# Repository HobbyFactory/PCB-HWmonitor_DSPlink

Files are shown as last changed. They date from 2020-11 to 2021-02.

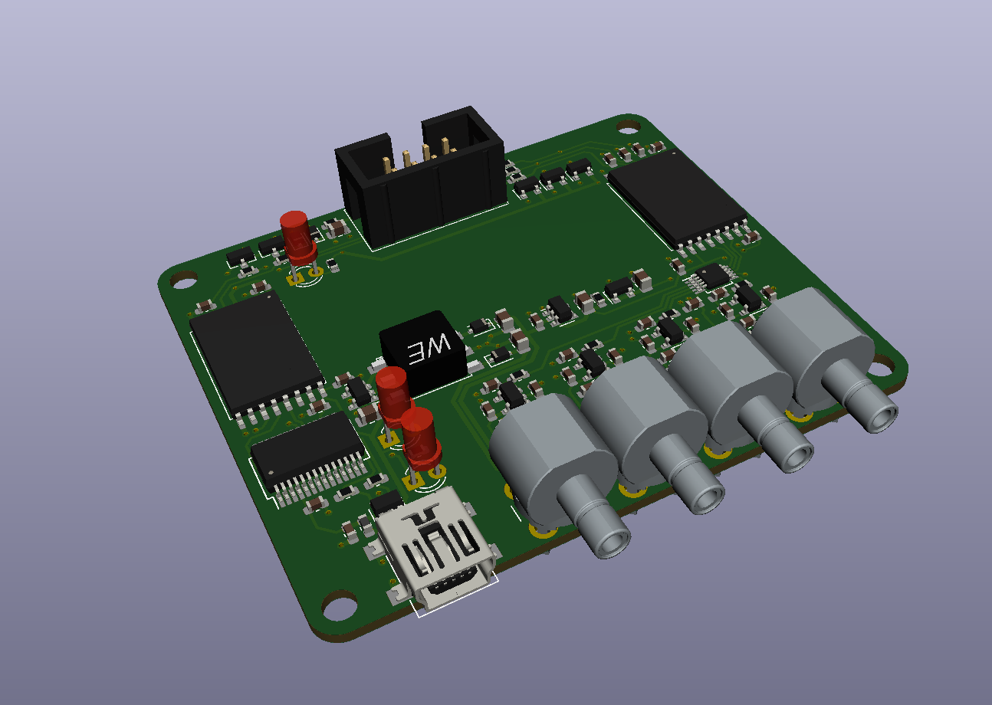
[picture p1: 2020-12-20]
gerber/picutre.PNG

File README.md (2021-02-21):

# HWmonitor & DSPlink

This is a debug tool, for visualizing digital signals from DSP or Microcontroller on Oscilloscope screen. In adition contains USB<->Serial converter to allow debug 
communication with target device.

block_diagram

Heart of the device is fast SPI D/A converter AD5324ARMZ, converting 4 channels into analog values, post processed by operational amplifiers. High voltage 8kVrms (ISO78XXDWW) galvanic isolation is provided between all inputs/outputs, to ensure safe debug experience, especially with high voltage power converters. 

Schematic, PCB project in KiCad and BOM are included in this repository. Device does not require any firmware for operation.

Model of the box optimized for 3D printer you can find here:
https://www.thingiverse.com/thing:4769601

If you are interested, send me the message, I still have some PCBs left from JLC.PCB. Assembled and tested version is available too.

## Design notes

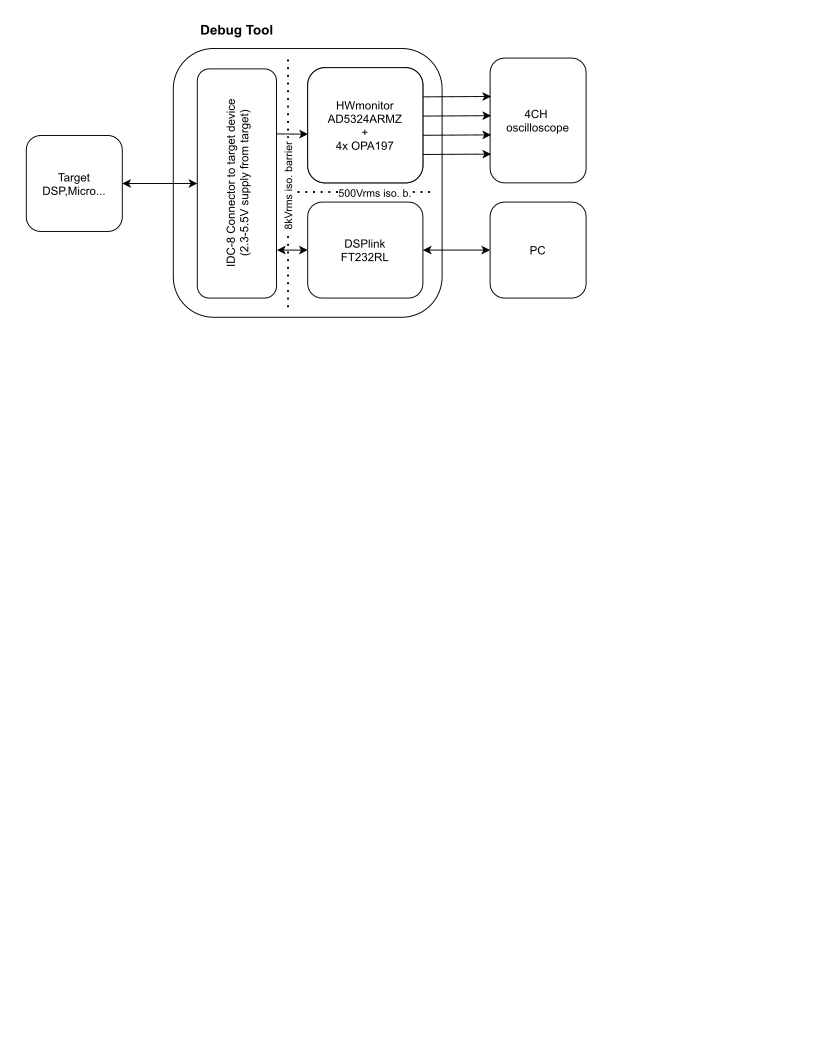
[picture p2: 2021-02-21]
blockd/png.png

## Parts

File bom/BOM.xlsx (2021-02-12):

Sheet: by MPNs
Item | Qty | Reference(s) | Value | Footprint | MPN
1 | 22 | C1, C5, C6, C10, C11, C12, C13, C14, C19, C20, C21, C22, C23, C28, C29, C30, C31, C32, C33, C34, C35, C36 | 100nF/50V | Capacitor_SMD:C_0603_1608Metric
2 | 6 | C2, C9, C15, C16, C17, C18 | 10uF/16V | Capacitor_SMD:C_0805_2012Metric | CC0805MKX7R7BB106
3 | 4 | C3, C4, C7, C8 | - | Capacitor_SMD:C_0603_1608Metric | -
4 | 4 | C24, C25, C26, C27 | 68pF/50V | Capacitor_SMD:C_0603_1608Metric
5 | 5 | D1, D3, D6, D7, D8 | BAT54S | Package_TO_SOT_SMD:SOT-23 | BAT54S
6 | 3 | D2, D11, D12 | PMEG6010CEJ | Diode_SMD:D_SOD-323F | PMEG6010CEJ
7 | 1 | D4 | 5.1V/200mW | Diode_SMD:D_SOD-323F | MM3Z5V1C
8 | 3 | D5, D9, D10 | RED | LED_THT:LED_D3.0mm_FlatTop | WP424SRDT
9 | 4 | H1, H2, H3, H4 | MountingHole | MountingHole:MountingHole_3.2mm_M3 | PHANTOM
10 | 1 | J1 | Mini USB-B | Connector_USB:USB_Mini-B_Lumberg_2486_01_Horizontal | 65100516121
11 | 1 | J2 | IDC-Header 2x4 | Connector_IDC:IDC-Header_2x04_P2.54mm_Vertical | 61200821621
12 | 1 | L1 | 1k@100MHz | Inductor_SMD:L_0603_1608Metric | 742792664
13 | 13 | R1, R2, R5, R6, R7, R11, R12, R13, R14, R23, R24, R25, R26 | 10R | Resistor_SMD:R_0603_1608Metric
14 | 1 | R3 | 27R | Resistor_SMD:R_0603_1608Metric
15 | 2 | R4, R8, R9 | 270R | Resistor_SMD:R_0603_1608Metric
16 | 1 | R10 | 750R | Resistor_SMD:R_0603_1608Metric
17 | 8 | R15, R16, R17, R18, R19, R20, R21, R22 | 10k | Resistor_SMD:R_0603_1608Metric
18 | 2 | R27, R28 | 47R | Resistor_SMD:R_0603_1608Metric
19 | 1 | T1 | 760390014 | #MyLibrary:Wuerth_760390014 | 760390014
20 | 1 | U1 | FT232RL | Package_SO:SSOP-28_5.3x10.2mm_P0.65mm | FT232RL
21 | 1 | U2 | ISO7830DWW | #MyLibrary:SOIC-16DWW | ISO7830DWW
22 | 1 | U3 | ISO7821DWW | #MyLibrary:SOIC-16DWW | ISO7821DWW
23 | 1 | U4 | SN6501DBVR | Package_TO_SOT_SMD:SOT-23-5 | SN6501DBVR
24 | 1 | U5 | TL431BCDBZ | Package_TO_SOT_SMD:SOT-23 | TL431BCDBZ
25 | 1 | U6 | AD5324ARMZ | Package_SO:MSOP-10_3x3mm_P0.5mm | AD5324ARMZ
26 | 1 | U7 | TLV70450DBVT | Package_TO_SOT_SMD:SOT-23-5 | TLV70450DBVT
27 | 4 | U8, U9, U10, U11 | OPA197xDBV | Package_TO_SOT_SMD:SOT-23-5 | OPA197IDBV
28 | 1 | U12 | USBLC6-2SC6 | Package_TO_SOT_SMD:SOT-23-6 | USBLC6-2SC6
29 | 4 | X1, X2, X3, X4 | Conn_Coaxial | #MyLibrary:Connector_131-3701-301 | 131-3701-301 OR 731000103

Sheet: by Components
Reference(s) | Value | MPN
C1 | 100nF/50V
C2 | 10uF/16V | CC0805MKX7R7BB106
C3 | NM
C4 | NM
C5 | 100nF/50V
C6 | 100nF/50V
C7 | NM
C8 | NM
C9 | 10uF/16V | CC0805MKX7R7BB106
C10 | 100nF/50V
C11 | 100nF/50V
C12 | 100nF/50V
C13 | 100nF/50V
C14 | 100nF/50V
C15 | 10uF/16V | CC0805MKX7R7BB106
C16 | 10uF/16V | CC0805MKX7R7BB106
C17 | 10uF/16V | CC0805MKX7R7BB106
C18 | 10uF/16V | CC0805MKX7R7BB106
C19 | 100nF/50V
C20 | 100nF/50V
C21 | 100nF/50V
C22 | 100nF/50V
C23 | 100nF/50V
C24 | 68pF/50V
C25 | 68pF/50V
C26 | 68pF/50V
C27 | 68pF/50V
C28 | 100nF/50V
C29 | 100nF/50V
C30 | 100nF/50V
C31 | 100nF/50V
C32 | 100nF/50V
C33 | 100nF/50V
C34 | 100nF/50V
C35 | 100nF/50V
C36 | 100nF/50V
D1 | BAT54S | BAT54S
D2 | PMEG6010CEJ | PMEG6010CEJ
D3 | BAT54S | BAT54S
D4 | 5.1V/200mW | MM3Z5V1C
D5 | RED | WP424SRDT
D6 | BAT54S | BAT54S
D7 | BAT54S | BAT54S
D8 | BAT54S | BAT54S
D9 | RED | WP424SRDT
D10 | RED | WP424SRDT
D11 | PMEG6010CEJ | PMEG6010CEJ
D12 | PMEG6010CEJ | PMEG6010CEJ
H1 | MountingHole | PHANTOM
H2 | MountingHole | PHANTOM
H3 | MountingHole | PHANTOM
H4 | MountingHole | PHANTOM
J1 | Mini USB-B | 65100516121
J2 | IDC-Header 2x4 | 61200821621
L1 | 1k@100MHz | 742792664
R1 | 10R
R2 | 10R
R3 | 27R
R4 | 10R
R5 | 10R
R6 | 10R
R7 | 10R
R8 | 270R
R9 | 270R
R10 | 750R
R11 | 10R
R12 | 10R
R13 | 10R
R14 | 10R
R15 | 10k
R16 | 10k
R17 | 10k
R18 | 10k
R19 | 10k
R20 | 10k
R21 | 10k
R22 | 10k
R23 | 10R
R24 | 10R
R25 | 10R
R26 | 10R
R27 | 47R
R28 | 47R
T1 | 760390014 | 760390014
U1 | FT232RL | FT232RL
U2 | ISO7830DWW | ISO7830DWW
U3 | ISO7821DWW | ISO7821DWW
U4 | SN6501DBVR | SN6501DBVR
U5 | TL431BCDBZ | TL431BCDBZ
U6 | AD5324ARMZ | AD5324ARMZ
U7 | TLV70450DBVT | TLV70450DBVT
U8 | OPA197xDBV | OPA197IDBV
U9 | OPA197xDBV | OPA197IDBV
U10 | OPA197xDBV | OPA197IDBV
U11 | OPA197xDBV | OPA197IDBV
U12 | USBLC6-2SC6 | USBLC6-2SC6
X1 | Conn_Coaxial | 131-3701-301
X2 | Conn_Coaxial | 131-3701-301
X3 | Conn_Coaxial | 131-3701-301
X4 | Conn_Coaxial | 131-3701-301

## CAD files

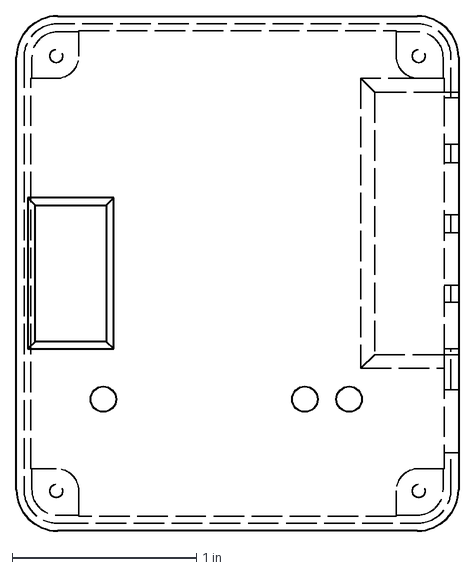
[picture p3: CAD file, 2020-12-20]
cad/box.dxf
2.40 x 2.80 in

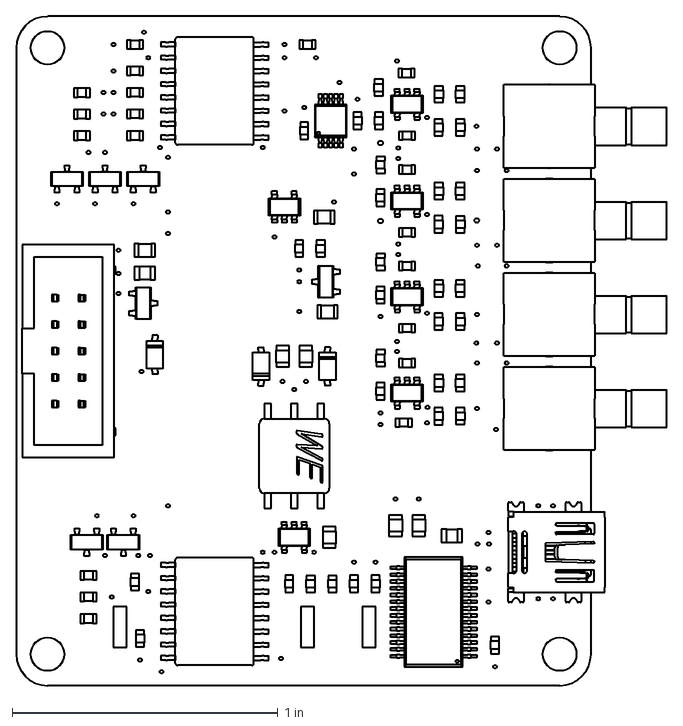
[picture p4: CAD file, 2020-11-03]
cad/HWmonitor v14_BelConnectors.dxf
2.45 x 2.52 in

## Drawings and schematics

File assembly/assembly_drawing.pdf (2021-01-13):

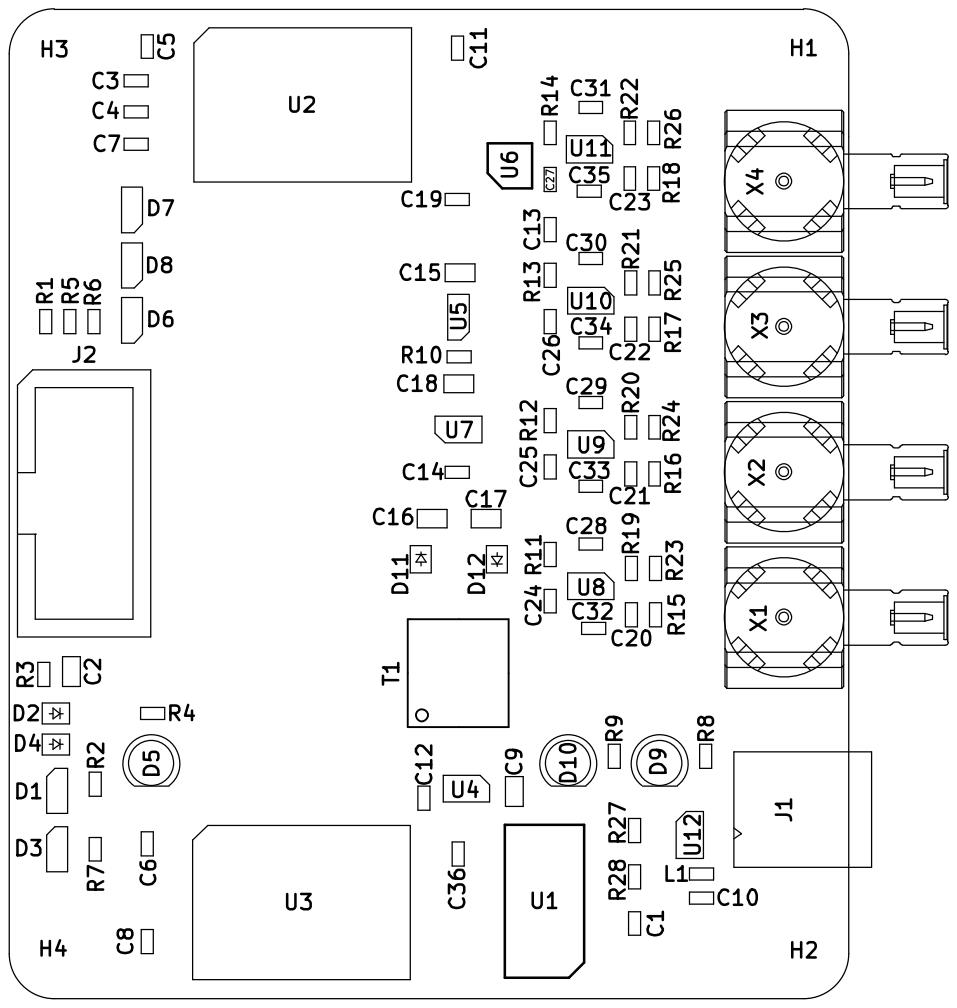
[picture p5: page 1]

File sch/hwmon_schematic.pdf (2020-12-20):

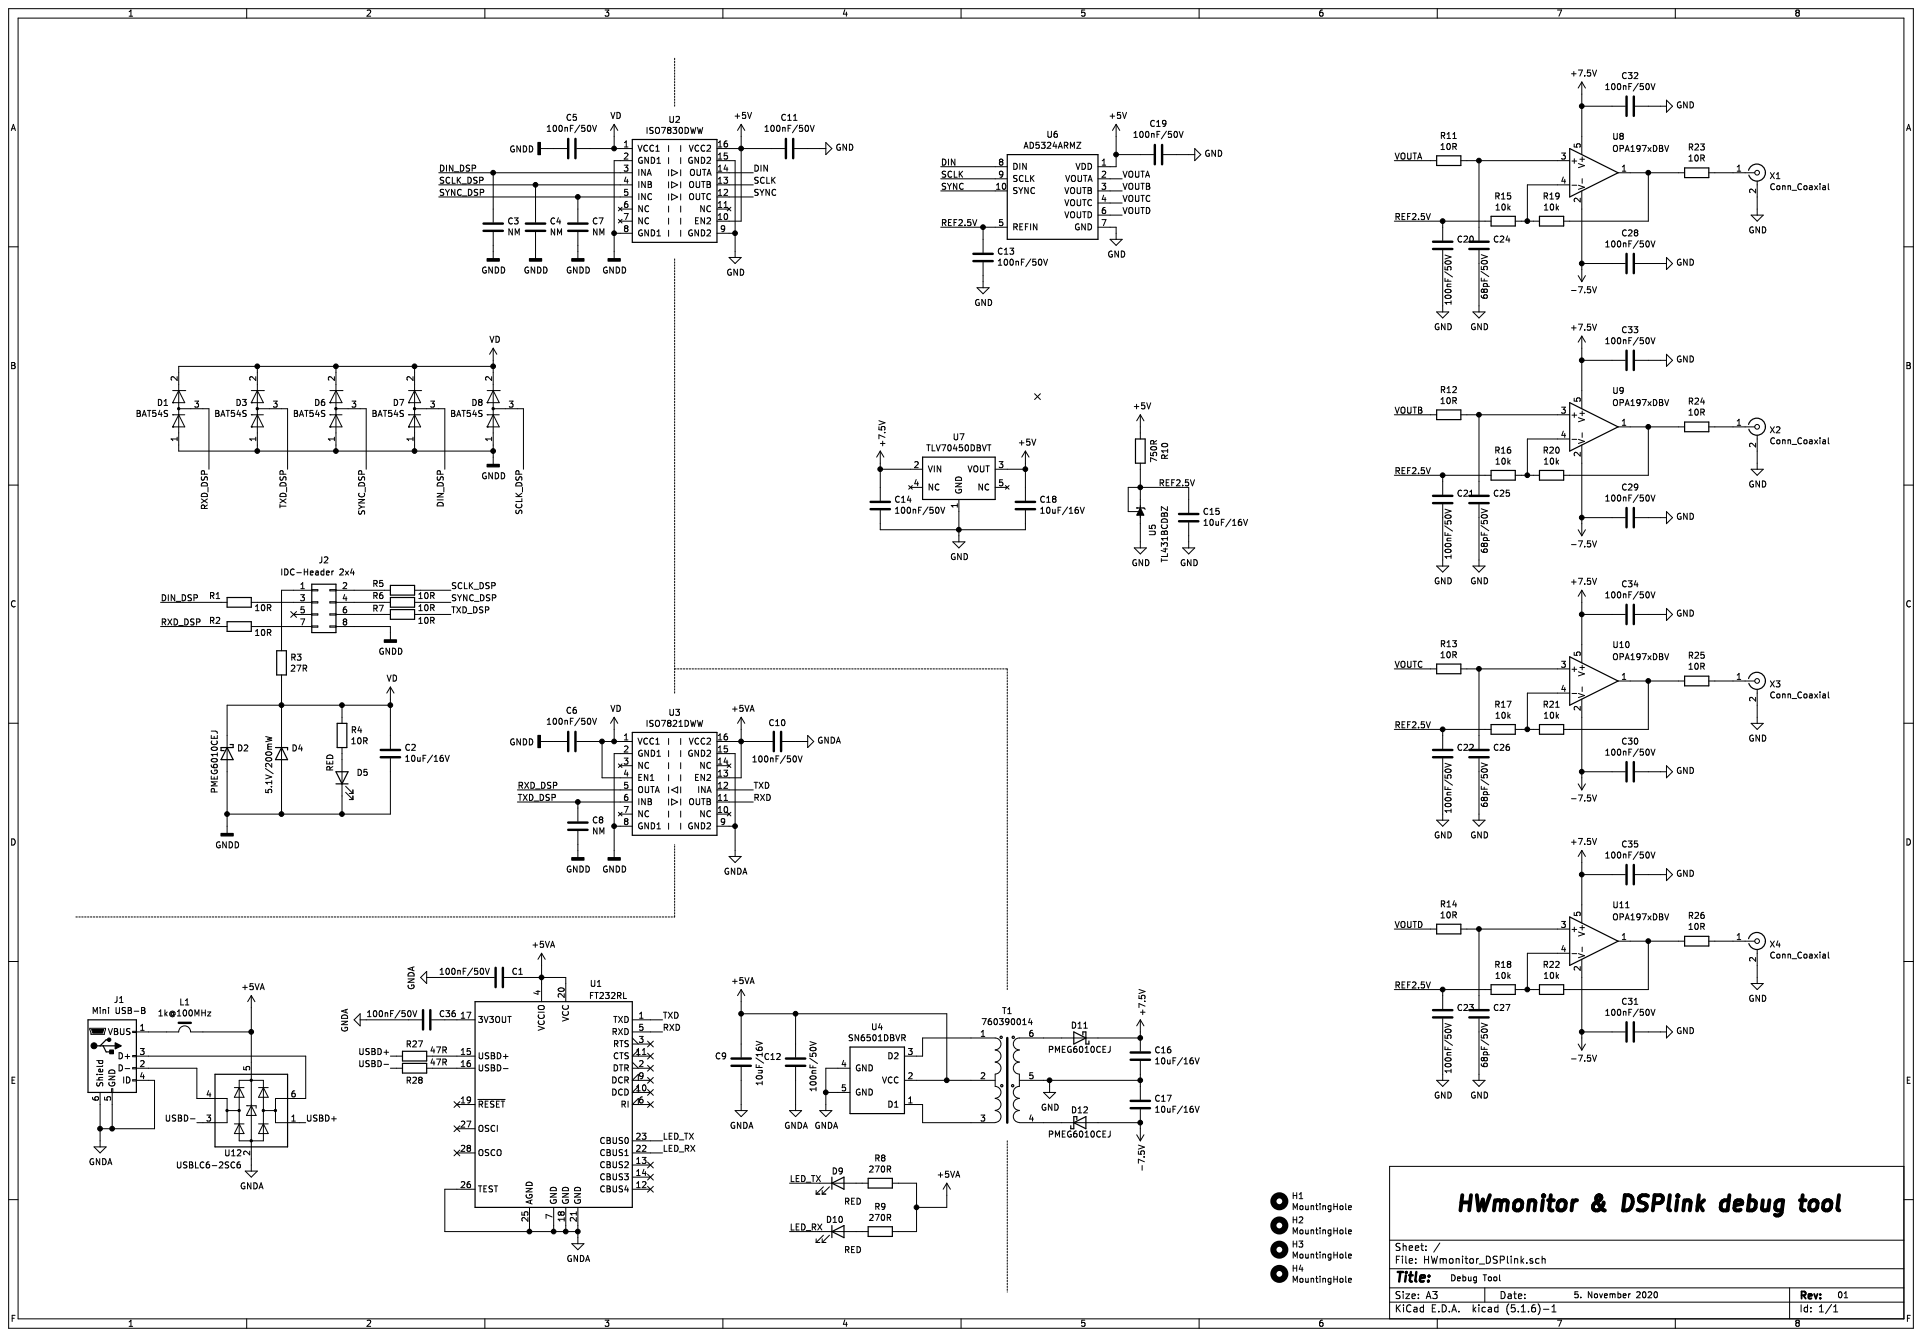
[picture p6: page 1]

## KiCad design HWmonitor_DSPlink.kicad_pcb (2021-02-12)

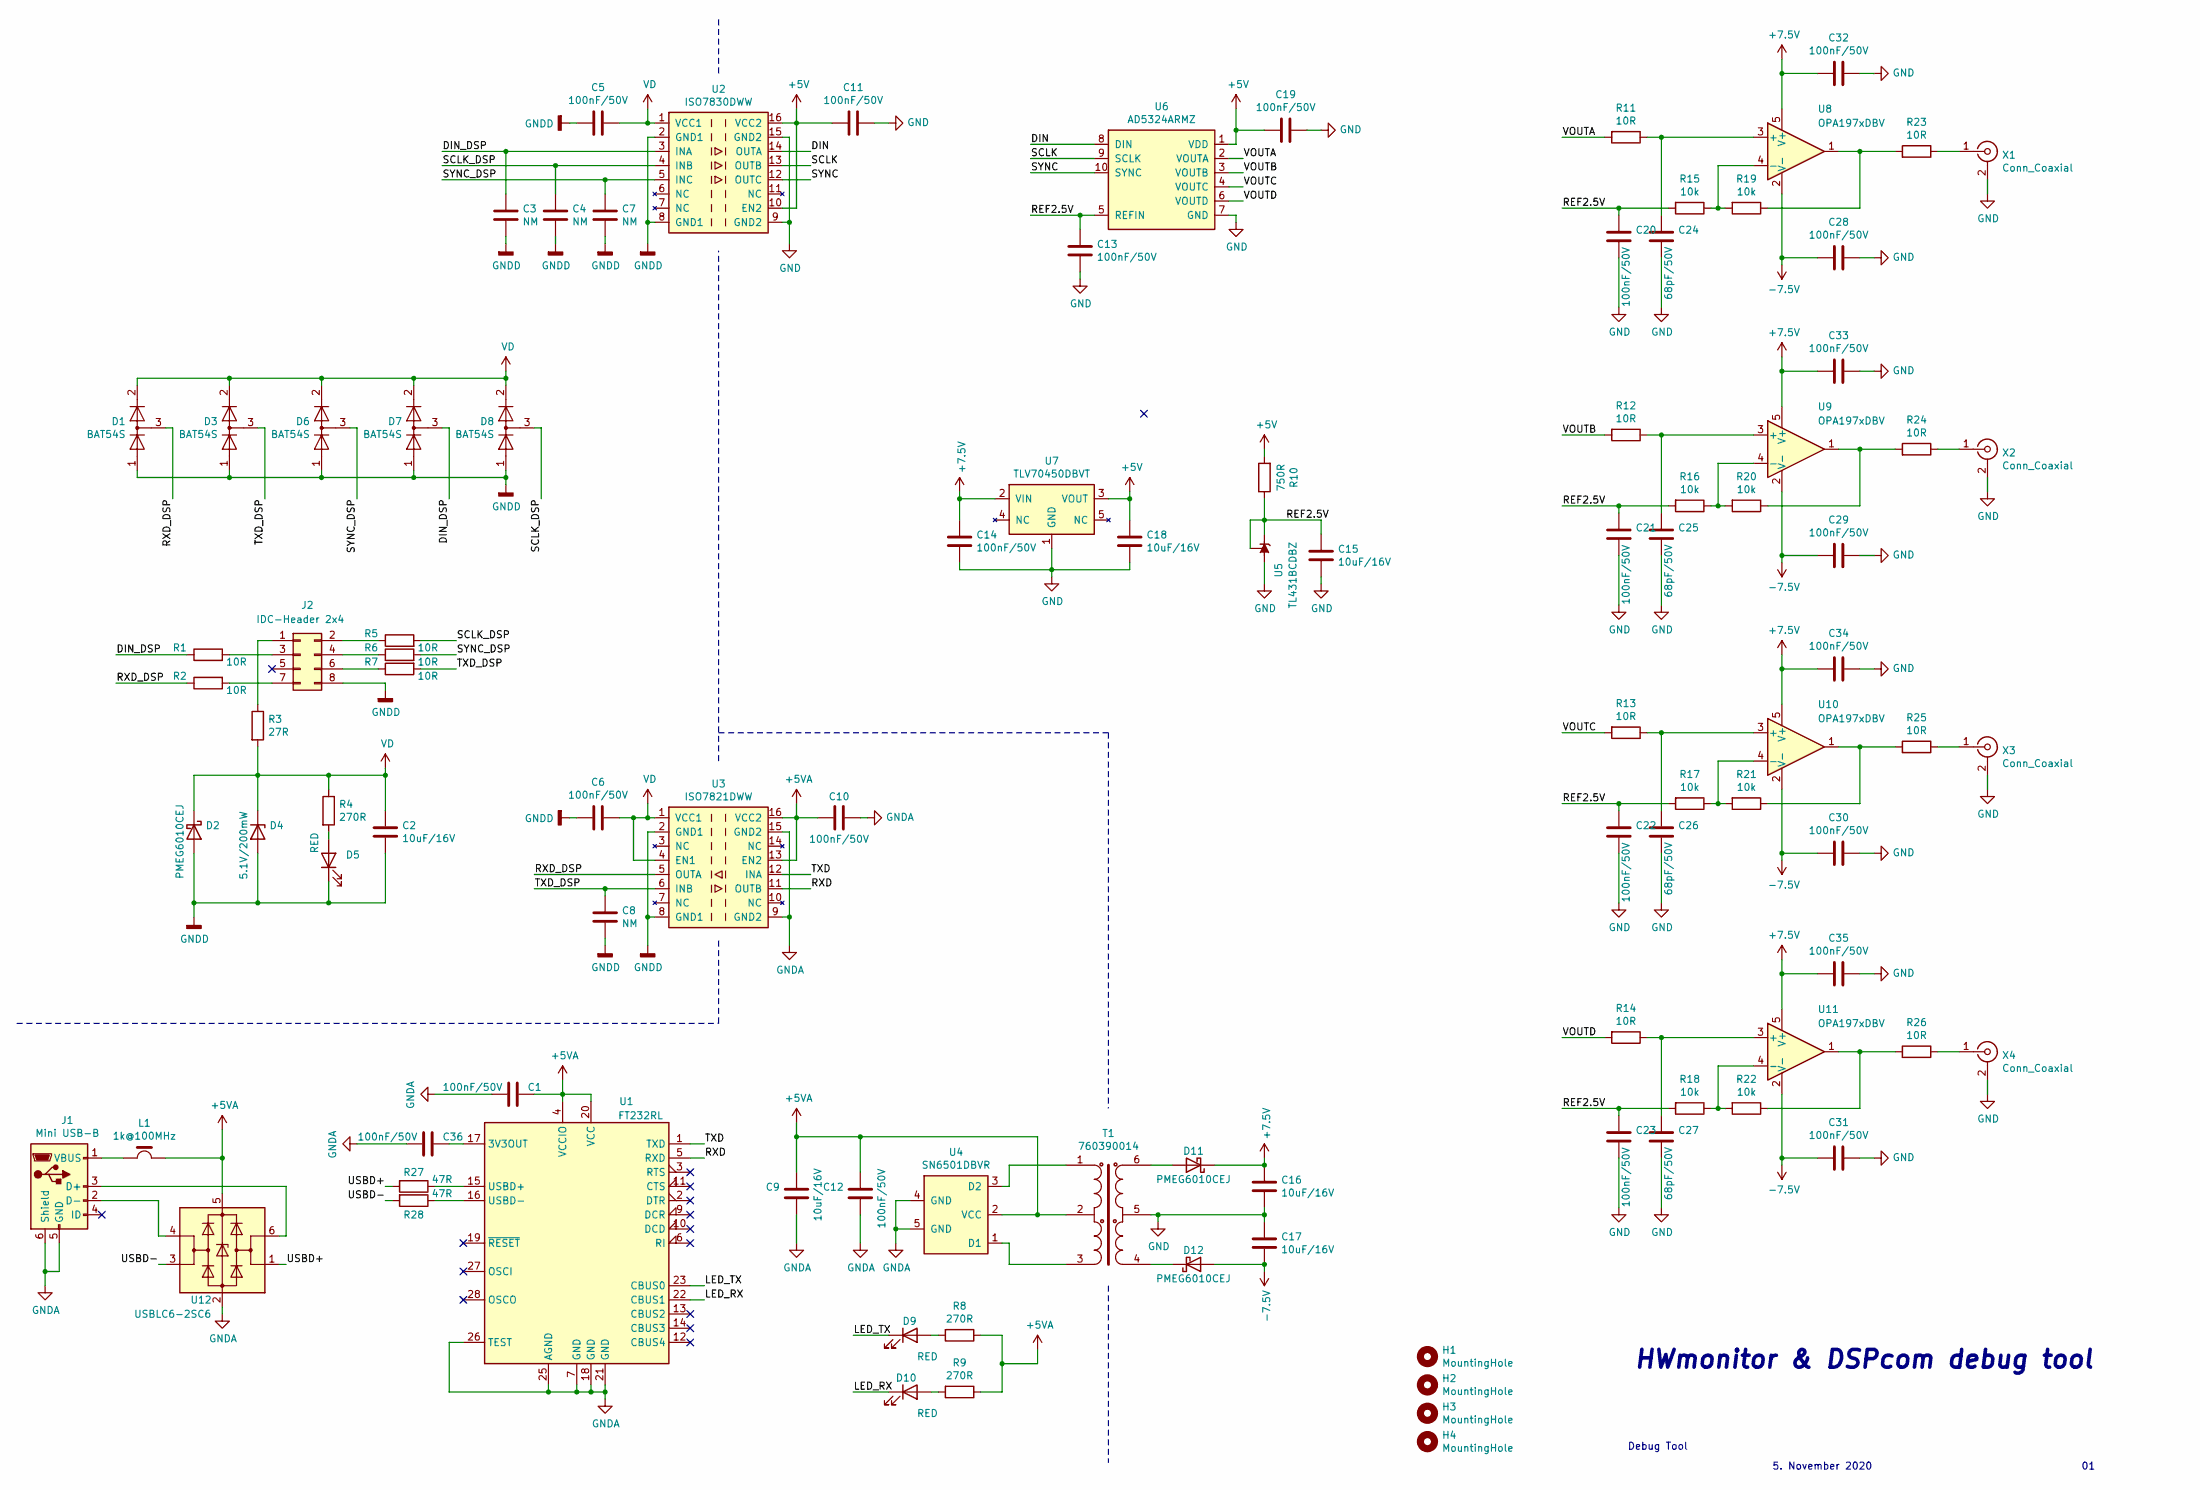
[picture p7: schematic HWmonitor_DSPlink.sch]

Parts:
C1, C5, C6, C10, C11, C12, C13, C14, C19, C20, C21, C22, C23, C28, C29, C30, C31, C32, C33, C34, C35, C36: 100nF/50V; C_0603_1608Metric
C2, C9, C15, C16, C17, C18: 10uF/16V; C_0805_2012Metric; MPN CC0805MKX7R7BB106
C3, C4, C7, C8: NM; C_0603_1608Metric
C24, C25, C26, C27: 68pF/50V; C_0603_1608Metric
D1, D3, D6, D7, D8: BAT54S; SOT-23; MPN BAT54S
D2, D11, D12: PMEG6010CEJ; D_SOD-323F; MPN PMEG6010CEJ
D4: 5.1V/200mW; D_SOD-323F; MPN MM3Z5V1C
D5, D9, D10: RED; LED_D3.0mm_FlatTop; MPN WP424SRDT
H1, H2, H3, H4: MountingHole; MountingHole_3.2mm_M3; MPN PHANTOM
J1: Mini USB-B; USB_Mini-B_Lumberg_2486_01_Horizontal; MPN 65100516121
J2: IDC-Header 2x4; IDC-Header_2x04_P2.54mm_Vertical; MPN 61200821621
L1: 1k@100MHz; L_0603_1608Metric; MPN 742792664
R1, R2, R5, R6, R7, R11, R12, R13, R14, R23, R24, R25, R26: 10R; R_0603_1608Metric
R3: 27R; R_0603_1608Metric
R4, R8, R9: 270R; R_0603_1608Metric
R10: 750R; R_0603_1608Metric
R15, R16, R17, R18, R19, R20, R21, R22: 10k; R_0603_1608Metric
R27, R28: 47R; R_0603_1608Metric
T1: 760390014; Wuerth_760390014; MPN 760390014
U1: FT232RL; SSOP-28_5.3x10.2mm_P0.65mm; MPN FT232RL
U2: ISO7830DWW; SOIC-16DWW; MPN ISO7830DWW
U3: ISO7821DWW; SOIC-16DWW; MPN ISO7821DWW
U4: SN6501DBVR; SOT-23-5; MPN SN6501DBVR
U5: TL431BCDBZ; SOT-23; MPN TL431BCDBZ
U6: AD5324ARMZ; MSOP-10_3x3mm_P0.5mm; MPN AD5324ARMZ
U7: TLV70450DBVT; SOT-23-5; MPN TLV70450DBVT
U8, U9, U10, U11: OPA197xDBV; SOT-23-5; MPN OPA197IDBV
U12: USBLC6-2SC6; SOT-23-6; MPN USBLC6-2SC6
X1, X2, X3, X4: Conn_Coaxial; Connector_131-3701-301; MPN 131-3701-301

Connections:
+5V: C11.1, C18.2, C19.1, R10.2, U2.10 (EN2), U2.16 (VCC2), U6.1 (VDD), U7.3 (VOUT)
+5VA: C1.2, C9.2, C10.1, C12.1, L1.2, R8.1, R9.1, T1.2, U1.4 (VCCIO), U1.20 (VCC), U3.13 (EN2), U3.16 (VCC2), U4.2 (VCC), U12.5 (VBUS)
+7.5V: C14.2, C16.2, C32.2, C33.2, C34.2, C35.2, D11.1 (K), U7.2 (VIN), U8.5 (V+), U9.5 (V+), U10.5 (V+), U11.5 (V+)
-7.5V: C17.1, C28.2, C29.2, C30.2, C31.2, D12.2 (A), U8.2 (V-), U9.2 (V-), U10.2 (V-), U11.2 (V-)
/DIN: U2.14 (OUTA), U6.8 (DIN)
/DIN_DSP: C3.2, D7.3 (K), R1.1, U2.3 (INA)
/LED_RX: D10.1 (K), U1.22 (CBUS1)
/LED_TX: D9.1 (K), U1.23 (CBUS0)
/REF2.5V: C13.2, C15.2, C20.2, C21.2, C22.2, C23.2, R10.1, R15.2, R16.2, R17.2, R18.2, U5.1 (K), U5.2 (REF), U6.5 (REFIN)
/RXD: U1.5 (RXD), U3.11 (OUTB)
/RXD_DSP: D1.3 (K), R2.1, U3.5 (OUTA)
/SCLK: U2.13 (OUTB), U6.9 (SCLK)
/SCLK_DSP: C4.2, D8.3 (K), R5.2, U2.4 (INB)
/SYNC: U2.12 (OUTC), U6.10 (SYNC)
/SYNC_DSP: C7.2, D6.3 (K), R6.2, U2.5 (INC)
/TXD: U1.1 (TXD), U3.12 (INA)
/TXD_DSP: C8.2, D3.3 (K), R7.2, U3.6 (INB)
/USBD+: R27.2, U12.1 (I/O1)
/USBD-: R28.2, U12.3 (I/O2)
/VOUTA: R11.2, U6.2 (VOUTA)
/VOUTB: R12.2, U6.3 (VOUTB)
/VOUTC: R13.2, U6.4 (VOUTC)
/VOUTD: R14.2, U6.6 (VOUTD)
GND: C11.2, C13.1, C14.1, C15.1, C16.1, C17.2, C18.1, C19.2, C20.1, C21.1, C22.1, C23.1, C24.1, C25.1, C26.1, C27.1, C28.1, C29.1, C30.1, C31.1, C32.1, C33.1, C34.1, C35.1, T1.5, U2.9 (GND2), U2.15 (GND2), U5.3 (A), U6.7 (GND), U7.1 (GND), X1.2 (Ext), X2.2 (Ext), X3.2 (Ext), X4.2 (Ext)
GNDA: C1.1, C9.1, C10.2, C12.2, C36.1, J1.5 (GND), J1.6 (Shield), U1.7 (GND), U1.18 (GND), U1.21 (GND), U1.25 (AGND), U1.26 (TEST), U3.9 (GND2), U3.15 (GND2), U4.4 (GND), U4.5 (GND), U12.2 (GND)
GNDD: C2.1, C3.1, C4.1, C5.1, C6.1, C7.1, C8.1, D1.1 (K), D2.2 (A), D3.1 (K), D4.2 (A), D5.1 (K), D6.1 (K), D7.1 (K), D8.1 (K), J2.8, U2.2 (GND1), U2.8 (GND1), U3.2 (GND1), U3.8 (GND1)
unnamed: C24.2, R11.1, U8.3 (+)
unnamed: C25.2, R12.1, U9.3 (+)
unnamed: C26.2, R13.1, U10.3 (+)
unnamed: C27.2, R14.1, U11.3 (+)
unnamed: C36.2, U1.17 (3V3OUT)
unnamed: D5.2 (A), R4.2
unnamed: D9.2 (A), R8.2
unnamed: D10.2 (A), R9.2
unnamed: D11.2 (A), T1.6
unnamed: D12.1 (K), T1.4
unnamed: J1.1 (VBUS), L1.1
unnamed: J1.2 (D-), U12.4 (I/O2)
unnamed: J1.3 (D+), U12.6 (I/O1)
unnamed: J2.1, R3.1
unnamed: J2.2, R5.1
unnamed: J2.3, R1.2
unnamed: J2.4, R6.1
unnamed: J2.6, R7.1
unnamed: J2.7, R2.2
unnamed: R15.1, R19.2, U8.4 (-)
unnamed: R16.1, R20.2, U9.4 (-)
unnamed: R17.1, R21.2, U10.4 (-)
unnamed: R18.1, R22.2, U11.4 (-)
unnamed: R19.1, R23.2, U8.1
unnamed: R20.1, R24.2, U9.1
unnamed: R21.1, R25.2, U10.1
unnamed: R22.1, R26.2, U11.1
unnamed: R23.1, X1.1 (In)
unnamed: R24.1, X2.1 (In)
unnamed: R25.1, X3.1 (In)
unnamed: R26.1, X4.1 (In)
unnamed: R27.1, U1.15 (USBD+)
unnamed: R28.1, U1.16 (USBD-)
unnamed: T1.1, U4.3 (D2)
unnamed: T1.3, U4.1 (D1)
VD: C2.2, C5.2, C6.2, D1.2 (A), D2.1 (K), D3.2 (A), D4.1 (K), D6.2 (A), D7.2 (A), D8.2 (A), R3.2, R4.1, U2.1 (VCC1), U3.1 (VCC1), U3.4 (EN1)

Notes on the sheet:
5. November 2020
Debug Tool
HWmonitor & DSPcom debug tool

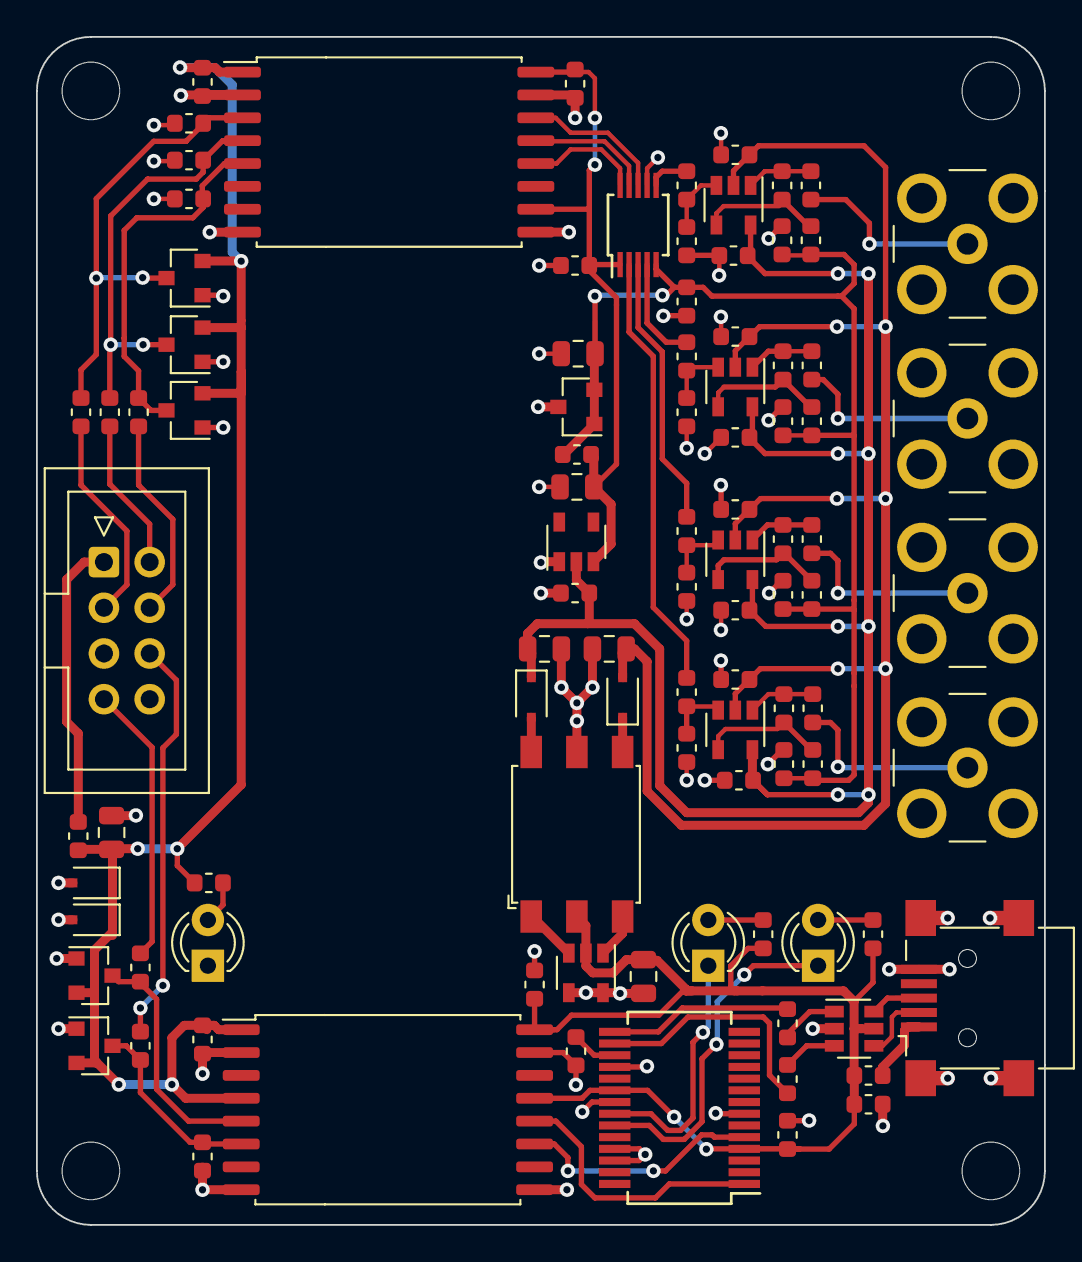
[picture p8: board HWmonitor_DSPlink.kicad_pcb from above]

Board: 2 copper layers, 56.0 x 66.0 mm, 100 parts (0 on the bottom side), 62 nets.

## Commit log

2020-11-05 Schematic drawn!
    [HWmonitor_DSPlink.sch, USBtoUART.sch]
2020-11-14 all footprints assigned
    [HWmonitor_DSPlink.kicad_pcb, HWmonitor_DSPlink.sch]
2020-11-20 initial placement
    [HWmonitor_DSPlink.kicad_pcb, HWmonitor_DSPlink.sch]
2020-12-05 placement, added USB input protection
    [HWmonitor_DSPlink.kicad_pcb, HWmonitor_DSPlink.sch]
2020-12-11 some initial routing done
    [HWmonitor_DSPlink.kicad_pcb]
2020-12-12 two parts routed
    [HWmonitor_DSPlink.kicad_pcb]
2020-12-13 routing finished, added all MPNs
    [HWmonitor_DSPlink.kicad_pcb, HWmonitor_DSPlink.sch]
2020-12-13 pdf schematic
2020-12-20 modified layout ftdi chip, added 3.3V capacitor
    [HWmonitor_DSPlink.kicad_pcb, HWmonitor_DSPlink.sch]
2020-12-20 last modifications, documents generated
    [BOM.xlsx, HWmonitor_DSPlink.kicad_pcb, HWmonitor_DSPlink.sch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]
2021-01-13 Added assembly drawing
    [HWmonitor_DSPlink.kicad_pcb]
2021-02-12 BOM bug, LED resistor to 270R
    [BOM.xlsx, HWmonitor_DSPlink.kicad_pcb, HWmonitor_DSPlink.sch]
